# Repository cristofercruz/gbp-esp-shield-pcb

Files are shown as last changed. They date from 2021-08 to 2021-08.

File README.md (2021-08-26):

# Game Boy WiFi Printer - D1 Mini Shield  



Enthusiasts on the [Game Boy Camera Club discord server](http://bit.ly/gbccd) have been working on a Game Boy Printer emulator project based on ESP8266 D1 mini boards. Taking inspiration from other projects like the [Gameboy Link Cable Breakout PCB](https://github.com/Palmr/gb-link-cable), I created this shield board to add a link connector and pinouts for an oled screen.

Here's a render of the PCB  
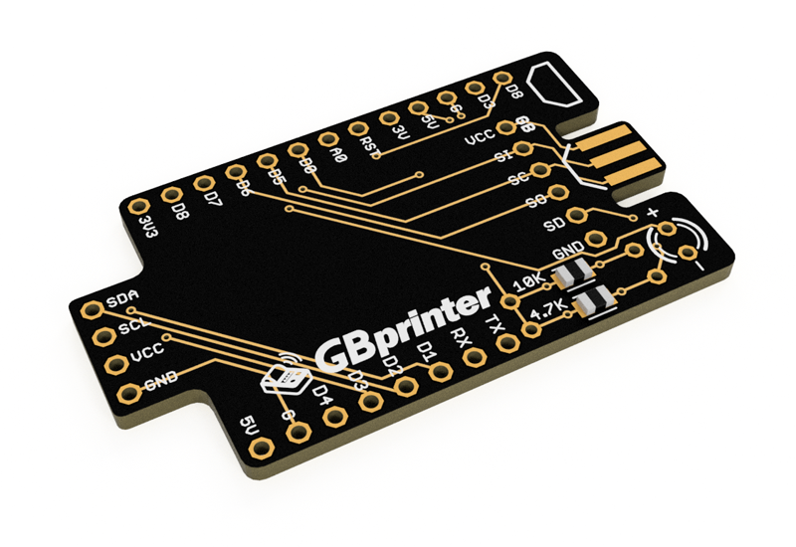
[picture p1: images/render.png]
3D render of the pcb design


# Recommended D1 mini Boards:  
**LILYGO TTGO D1 mini** (recommended) - https://www.aliexpress.com/item/4001144115302.html  
Embedded 16340 battery holder, embedded charge curcuit, and embedded power switch.

**LOLIN D1 mini Pro** - https://www.aliexpress.com/item/32724692514.html  
Embedded LiPo battery connector, embedded charge circuit. No embedded power switch.

**LOLIN D1 mini** - https://www.aliexpress.com/item/32529101036.html  
No battery connector, no charge curcit, and no power switch included.

# Assembled Printer Example  
Here's a photo of an assembled printer using a D1 mini Pro board:  
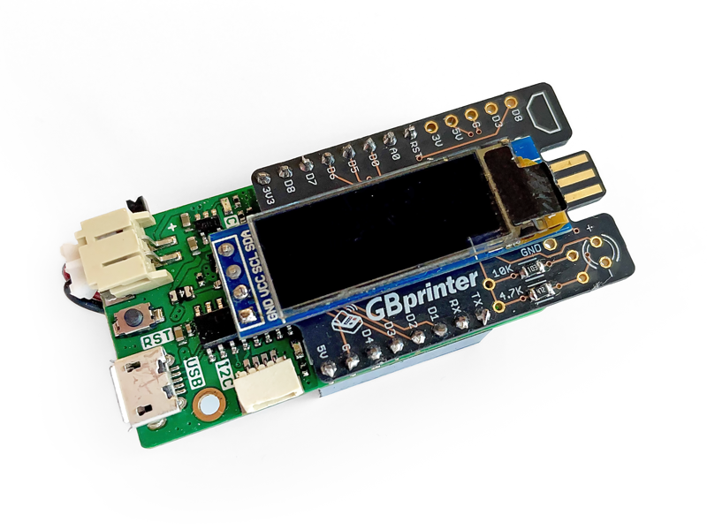
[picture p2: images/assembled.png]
Assembled printer using d1 mini pro


# Components  
Besides the ESP8266 board, this shield uses the following components:

* 1× 4.7kΩ resistor (*required for link detection*)
* 1x 10kΩ resistor (*required for link detection*)
* 1× 128×32 OLED display (*optional, recommended*)
* 1× 3.5mm LED (*optional*)

Placements for the components are clearly marked on the board's silkscreen. The resistors can be either through hole or surface mount type and can be placed either on the top OR bottom of the board.

# Compatible Software  
This shield breaks out appropriate pins for the Game Boy Link port that is part of the PCB itself. This hardware is suitable for both the [Arduino Game Boy Printer Emulator](https://github.com/mofosyne/arduino-gameboy-printer-emulator) as well as the [WiFi Game Boy Printer Emulator](https://github.com/HerrZatacke/wifi-gbp-emulator)

When using this with the WiFi Game Boy Printer Emulator, you can uncomment and adjust the pin on the following lines in your `config.h` file to detect a connected and powered on Game Boy to auto switch into print mode:  
```
// Sense boot mode lets you use the signal on pin GB_5V_OUT to determine printer/server mode
#define SENSE_BOOT_MODE
#define GB_5V_OUT 16
```

If you've added the optional OLED display, you can uncomment and adjust the pins on the following lines in your `config.h` file:  
```
// Uncomment if using an adafruit oled display
#define USE_OLED
// Alternative OLED Pins
#define OLED_SDA 4
#define OLED_SCL 5
```

# Usage 

When connecting a Game Boy Link cable to the shield, check the silkscreen for indicators on which side should be placed up. (The flat side of the connector should face down and the rounded side should face up, the same side as the OLED screen.)

You can get help with this project and find info on the software that runs on the ESP by joining the [Game Boy Camera Club discord server](http://bit.ly/gbccd)

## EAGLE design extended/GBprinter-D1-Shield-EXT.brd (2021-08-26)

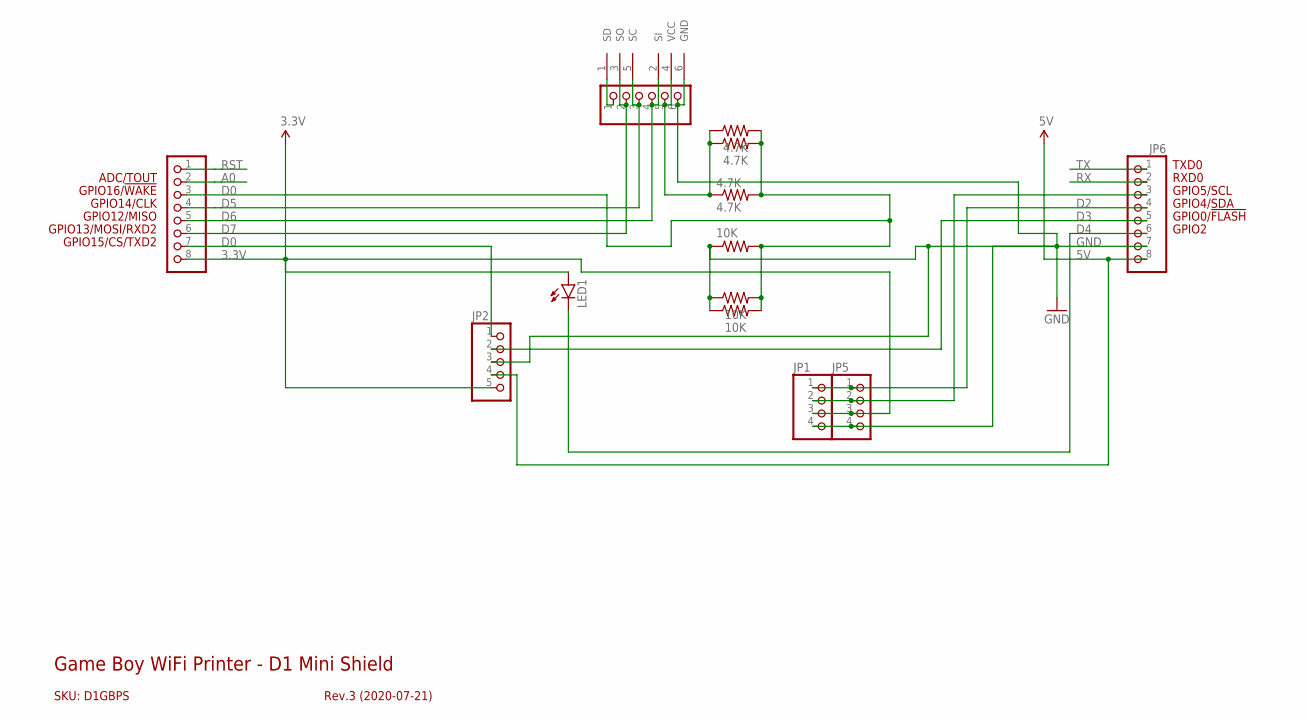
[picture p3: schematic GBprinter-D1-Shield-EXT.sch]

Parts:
4.7K: 4.7K; 0207/10
10K: 10K; 0207/10
JP1, JP5: PINHD-1X4/OCT; 1X04/OCT
JP2: PINHD-1X5/OCT; 1X05/OCT
JP3, JP6: PINHD-1X8/OCT; 1X08/OCT
JP4: PINHD-1X6/OCT; 1X06/OCT
LED1: LED3MM
R1, R5: 4.7K; RESC2012X65
R2, R3: 10K; RESC2012X65
U$2: GB-LINK-PADS; GB-LINK-PCB

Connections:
3.3V: JP1.3, JP2.5, JP3.8, JP5.3, LED1.A
5V: JP2.4, JP6.8
A0: JP3.2
D0: 4.7K.2, 10K.2, JP3.3, R1.2, R2.2, R3.2, R5.2
D1: JP1.2, JP5.2, JP6.3
D2: JP1.1, JP5.1, JP6.4
D3: JP2.2, JP6.5
D4: JP6.6, LED1.K (C)
D5: JP3.4, JP4.3, U$2.5 (SC)
D6: JP3.5, JP4.4, U$2.2 (SI)
D7: JP3.6, JP4.2, U$2.3 (SO)
D8: JP2.1, JP3.7
GND: 10K.1, JP1.4, JP2.3, JP4.6, JP5.4, JP6.7, R2.1, R3.1, U$2.6 (GND)
RST: JP3.1
RX: JP6.2
SD: 4.7K.1, JP4.5, R1.1, R5.1, U$2.4 (VCC)
TX: JP6.1
VCC: JP4.1, U$2.1 (SD)

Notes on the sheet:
GPIO2
GPIO0/!FLASH
GPIO12/MISO
GPIO4/SDA
GPIO5/SCL
RXD0
TXD0
GPIO13/MOSI/RXD2
GPIO14/CLK
GPIO15/CS/TXD2
GPIO16/!WAKE
SKU: D1GBPS
Game Boy WiFi Printer - D1 Mini Shield
Rev.3 (2020-07-21)
ADC/TOUT

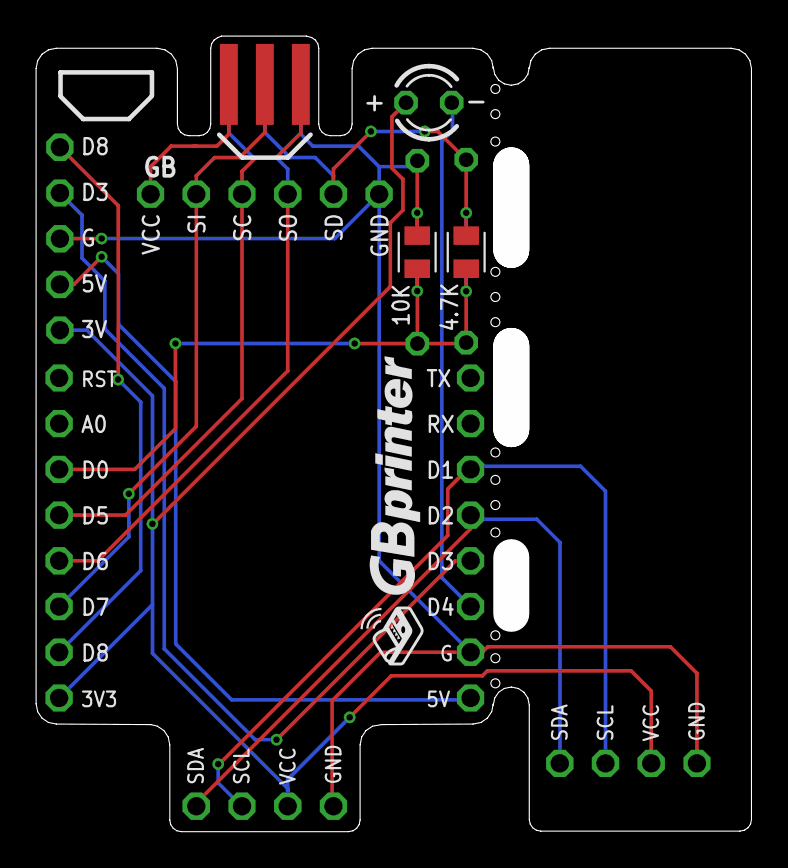
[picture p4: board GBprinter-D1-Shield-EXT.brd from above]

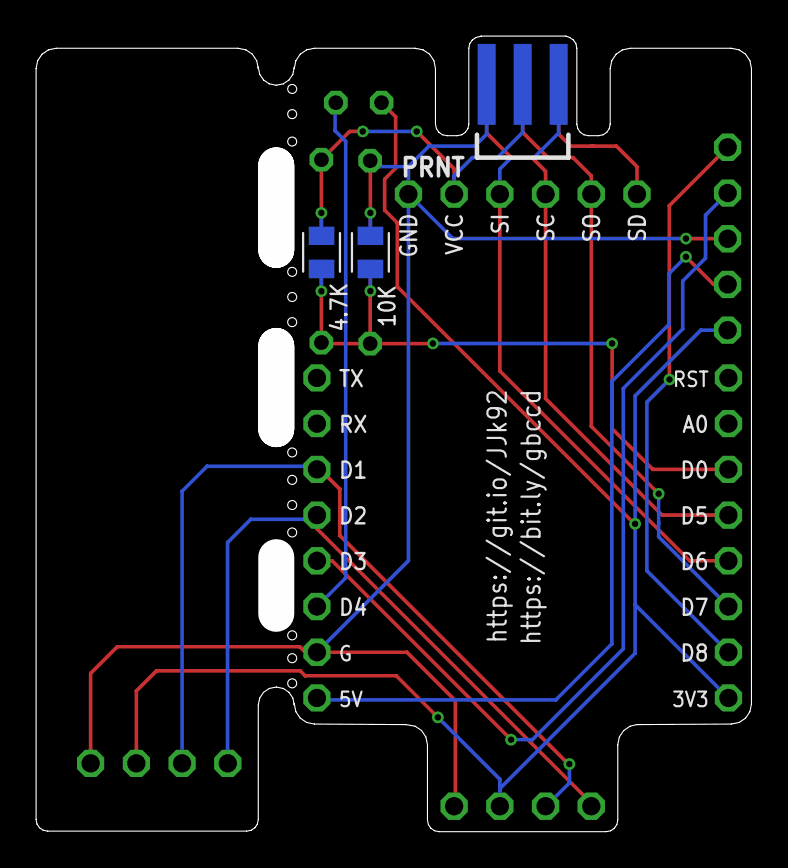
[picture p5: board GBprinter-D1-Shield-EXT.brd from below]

Board: 2 copper layers, 39.7 x 44.2 mm, 14 parts (4 on the bottom side), 14 nets.

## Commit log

2020-07-21 post eagle files and gerbers
2020-07-21 post eagle files, images and gerbers
    [GB-WP-D1.brd, GB-WP-D1.sch]
2020-07-21 expand gerbers
    [GB-WP-D1.drills.drills.xln, GB-WP-D1.slotdrills.slotdrills.xln, gerber_job.gbrjob]
2020-07-21 move gerbers
    [GB-WP-D1.drills.drills.xln, GB-WP-D1.slotdrills.slotdrills.xln, gerber_job.gbrjob]
2021-04-24 Update README.md
    Adds useful information when connecting the PCB
2021-08-26 Link detect switched to D0, 10K resistor added, resistors moved, cleaned up routing
    [GB-WP-D1.brd, GB-WP-D1.sch, GBprinter-D1-Shield-EXT.brd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]
2021-08-26 new assembled pic

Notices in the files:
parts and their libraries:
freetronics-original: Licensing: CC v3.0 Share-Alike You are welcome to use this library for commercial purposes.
